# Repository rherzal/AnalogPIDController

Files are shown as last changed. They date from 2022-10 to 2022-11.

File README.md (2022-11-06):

# This is the main repository for my measurements and actuators semester project

The project is a full design and implementation of an analog PID controller pcb, using only operational amplifiers for calculations, used to control a DC motor.

It uses 3 potentiometers for setting the 3 controller constants, one potentiometer for setting the command signal, and one potentiometer for angular feedback.

The PCB was manufactured with the help of a local electronics company from Baia Mare, [circuite-imprimate.ro](https://circuite-imprimate.ro/).

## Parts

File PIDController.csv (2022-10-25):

Source: | D:\OneDrive\OneDrive - Technical University of Cluj-Napoca\Toate\Anul2\PrimulSemestru\MA\ProiectMA\PIDController\PIDController.kicad_sch
Date: | 16/10/2022 14:33:03
Tool: | Eeschema (6.0.8)
Generator: | C:\Program Files\KiCad\6.0\bin\scripting\plugins/bom_csv_grouped_by_value.py
Component Count: | 24
Individual Components:
Item | Qty | Reference(s) | Value | LibPart | Footprint | Datasheet
 |  | C1 | 4.7u | Device:C | Capacitor_THT:C_Rect_L4.6mm_W3.8mm_P2.50mm_MKS02_FKP02 | ~
 |  | C2 | 4.7u | Device:C | Capacitor_THT:C_Rect_L4.6mm_W3.8mm_P2.50mm_MKS02_FKP02 | ~
 |  | J1 | Jack-DC | Connector:Jack-DC | Connector_BarrelJack:BarrelJack_GCT_DCJ200-10-A_Horizontal | ~
 |  | J2 | Jack-DC | Connector:Jack-DC | Connector_BarrelJack:BarrelJack_GCT_DCJ200-10-A_Horizontal | ~
 |  | J3 | Screw_Terminal_01x02 | Connector:Screw_Terminal_01x02 | TerminalBlock_RND:TerminalBlock_RND_205-00001_1x02_P5.00mm_Horizontal | ~
 |  | Q1 | BD433 | Transistor_BJT:BD433 | Package_TO_SOT_THT:TO-126-3_Vertical | http://www.cdil.com/datasheets/bd433_42.pdf
 |  | Q2 | BD434 | Transistor_BJT:BD434 | Package_TO_SOT_THT:TO-126-3_Vertical | http://www.cdil.com/datasheets/bd433_42.pdf
 |  | R1 | 10k | Device:R | Resistor_THT:R_Axial_DIN0207_L6.3mm_D2.5mm_P15.24mm_Horizontal | ~
 |  | R2 | 10k | Device:R | Resistor_THT:R_Axial_DIN0207_L6.3mm_D2.5mm_P15.24mm_Horizontal | ~
 |  | R3 | 10k | Device:R | Resistor_THT:R_Axial_DIN0207_L6.3mm_D2.5mm_P15.24mm_Horizontal | ~
 |  | R4 | 10k | Device:R | Resistor_THT:R_Axial_DIN0207_L6.3mm_D2.5mm_P15.24mm_Horizontal | ~
 |  | R5 | 100k | Device:R | Resistor_THT:R_Axial_DIN0207_L6.3mm_D2.5mm_P15.24mm_Horizontal | ~
 |  | R6 | 47k | Device:R | Resistor_THT:R_Axial_DIN0207_L6.3mm_D2.5mm_P15.24mm_Horizontal | ~
 |  | R7 | 10k | Device:R | Resistor_THT:R_Axial_DIN0207_L6.3mm_D2.5mm_P15.24mm_Horizontal | ~
 |  | R8 | 10k | Device:R | Resistor_THT:R_Axial_DIN0207_L6.3mm_D2.5mm_P15.24mm_Horizontal | ~
 |  | R9 | 10k | Device:R | Resistor_THT:R_Axial_DIN0207_L6.3mm_D2.5mm_P15.24mm_Horizontal | ~
 |  | R10 | 10k | Device:R | Resistor_THT:R_Axial_DIN0207_L6.3mm_D2.5mm_P15.24mm_Horizontal | ~
 |  | RV1 | 100k | Device:R_Potentiometer | Potentiometer_THT:Potentiometer_Piher_PC-16_Single_Horizontal | ~
 |  | RV2 | 100k | Device:R_Potentiometer | Potentiometer_THT:Potentiometer_Piher_PC-16_Single_Horizontal | ~
 |  | RV3 | 100k | Device:R_Potentiometer | Potentiometer_THT:Potentiometer_Piher_PC-16_Single_Horizontal | ~
 |  | RV4 | 100k | Device:R_Potentiometer | Potentiometer_THT:Potentiometer_Piher_PC-16_Single_Horizontal | ~
 |  | RV5 | 470k | Device:R_Potentiometer | Potentiometer_THT:Potentiometer_Piher_PC-16_Single_Horizontal | ~
 |  | U1 | LM324 | Amplifier_Operational:LM324 | Package_DIP:DIP-14_W7.62mm_Socket | http://www.ti.com/lit/ds/symlink/lm2902-n.pdf
 |  | U2 | LM324 | Amplifier_Operational:LM324 | Package_DIP:DIP-14_W7.62mm_Socket | http://www.ti.com/lit/ds/symlink/lm2902-n.pdf
Collated Components:
Item | Qty | Reference(s) | Value | LibPart | Footprint | Datasheet
1 | 2 | C1, C2 | 4.7u | Device:C | Capacitor_THT:C_Rect_L4.6mm_W3.8mm_P2.50mm_MKS02_FKP02 | ~
2 | 2 | J1, J2 | Jack-DC | Connector:Jack-DC | Connector_BarrelJack:BarrelJack_GCT_DCJ200-10-A_Horizontal | ~
3 | 1 | J3 | Screw_Terminal_01x02 | Connector:Screw_Terminal_01x02 | TerminalBlock_RND:TerminalBlock_RND_205-00001_1x02_P5.00mm_Horizontal | ~
4 | 1 | Q1 | BD433 | Transistor_BJT:BD433 | Package_TO_SOT_THT:TO-126-3_Vertical | http://www.cdil.com/datasheets/bd433_42.pdf
5 | 1 | Q2 | BD434 | Transistor_BJT:BD434 | Package_TO_SOT_THT:TO-126-3_Vertical | http://www.cdil.com/datasheets/bd433_42.pdf
6 | 8 | R1, R2, R3, R4, R7, R8, R9, R10 | 10k | Device:R | Resistor_THT:R_Axial_DIN0207_L6.3mm_D2.5mm_P15.24mm_Horizontal | ~
7 | 1 | R5 | 100k | Device:R | Resistor_THT:R_Axial_DIN0207_L6.3mm_D2.5mm_P15.24mm_Horizontal | ~
8 | 1 | R6 | 47k | Device:R | Resistor_THT:R_Axial_DIN0207_L6.3mm_D2.5mm_P15.24mm_Horizontal | ~
9 | 4 | RV1, RV2, RV3, RV4 | 100k | Device:R_Potentiometer | Potentiometer_THT:Potentiometer_Piher_PC-16_Single_Horizontal | ~
10 | 1 | RV5 | 470k | Device:R_Potentiometer | Potentiometer_THT:Potentiometer_Piher_PC-16_Single_Horizontal | ~
11 | 2 | U1, U2 | LM324 | Amplifier_Operational:LM324 | Package_DIP:DIP-14_W7.62mm_Socket | http://www.ti.com/lit/ds/symlink/lm2902-n.pdf

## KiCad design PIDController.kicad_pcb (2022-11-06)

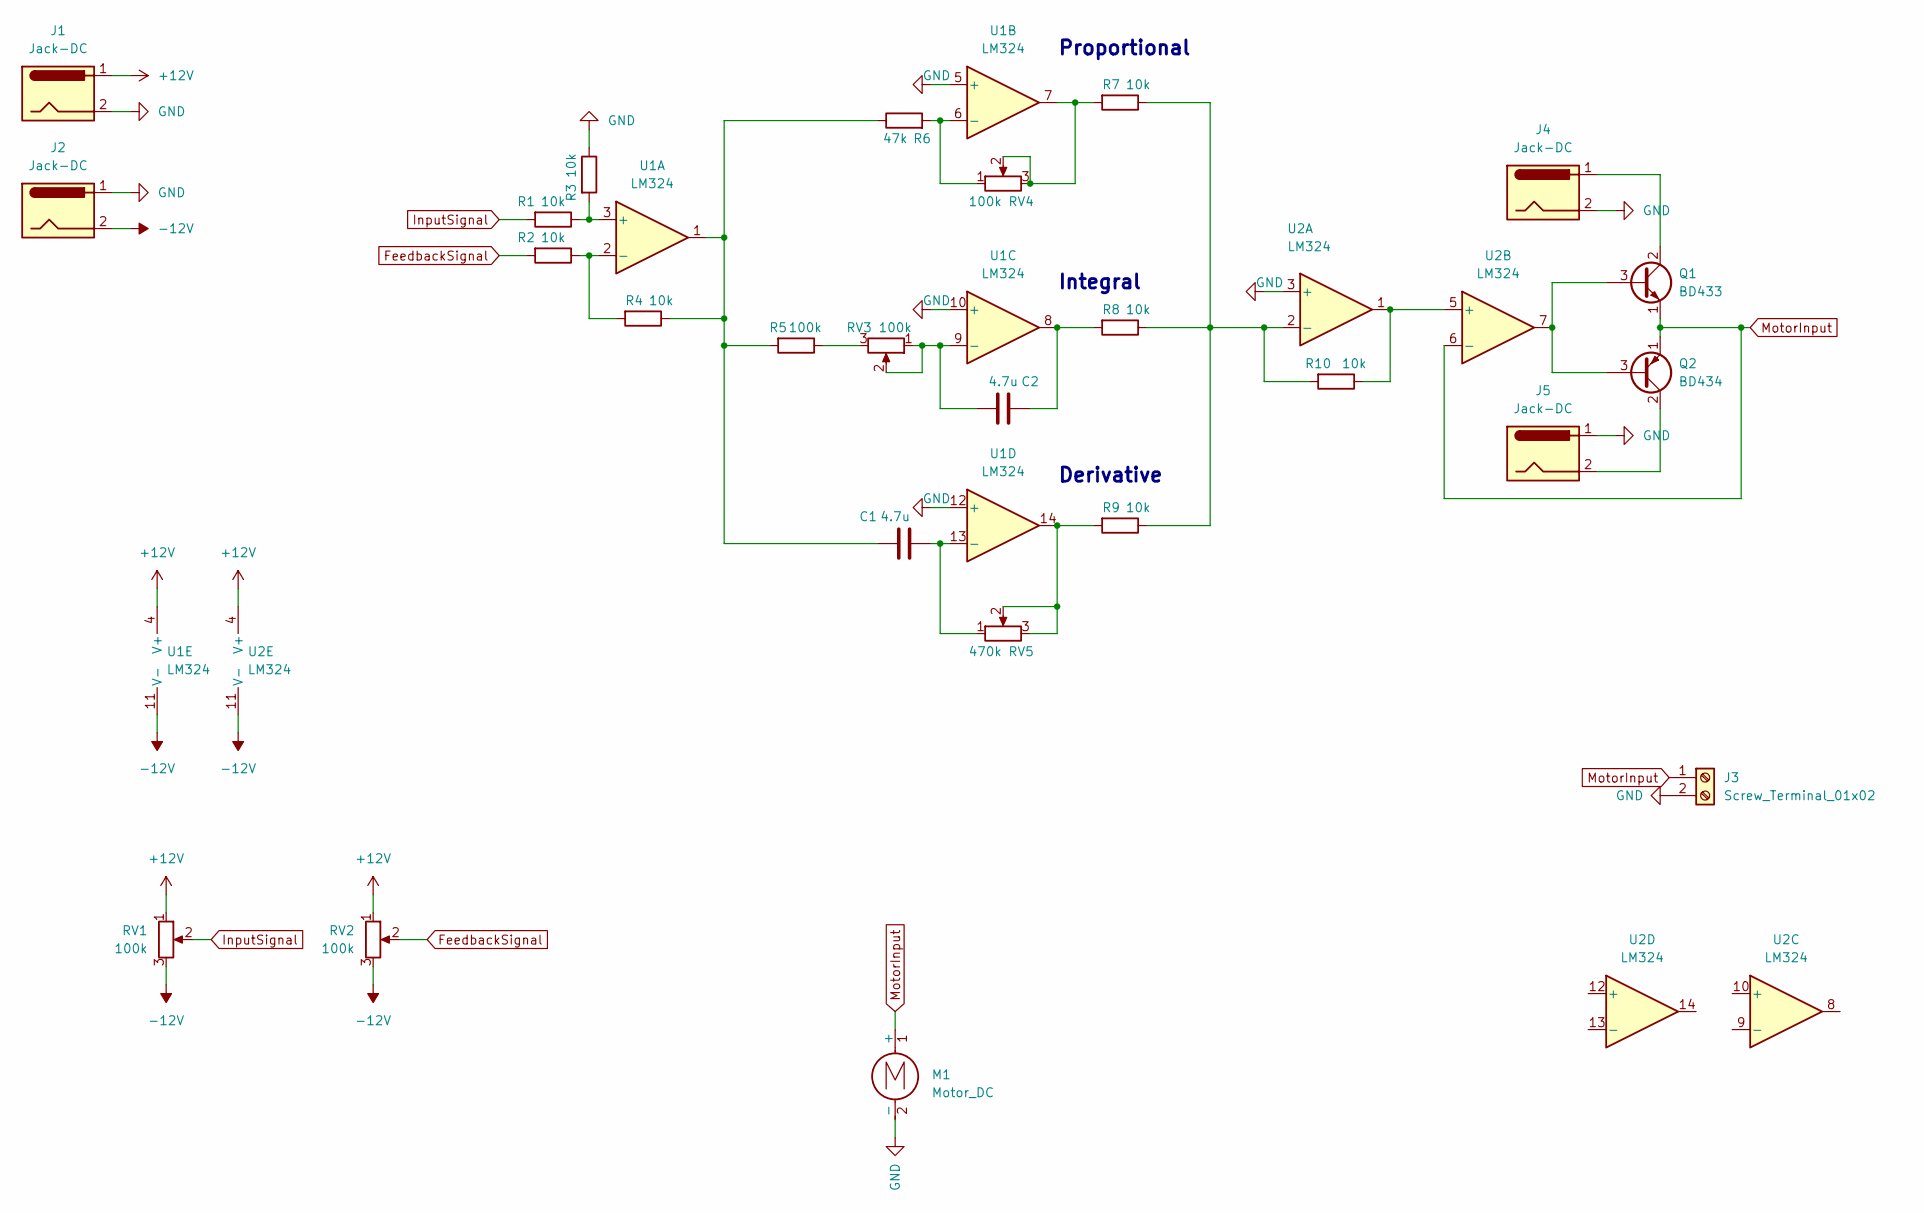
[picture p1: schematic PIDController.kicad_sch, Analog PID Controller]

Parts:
C1, C2: 4.7u; C_Rect_L4.6mm_W3.8mm_P2.50mm_MKS02_FKP02
J1, J2, J4, J5: Jack-DC; BarrelJack_GCT_DCJ200-10-A_Horizontal
J3: Screw_Terminal_01x02; TerminalBlock_RND_205-00001_1x02_P5.00mm_Horizontal
M1: Motor_DC; TerminalBlock_RND_205-00001_1x02_P5.00mm_Horizontal
Q1: BD433; TO-126-3_Vertical
Q2: BD434; TO-126-3_Vertical
R1, R2, R3, R4, R7, R8, R9, R10: 10k; R_Axial_DIN0207_L6.3mm_D2.5mm_P15.24mm_Horizontal
R5: 100k; R_Axial_DIN0207_L6.3mm_D2.5mm_P15.24mm_Horizontal
R6: 47k; R_Axial_DIN0207_L6.3mm_D2.5mm_P15.24mm_Horizontal
RV1, RV2, RV3, RV4: 100k; Potentiometer_Piher_PC-16_Single_Horizontal
RV5: 470k; Potentiometer_Piher_PC-16_Single_Horizontal
U1, U2: LM324; DIP-14_W7.62mm_Socket

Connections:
+12V: J1.1, RV1.1, RV2.1, U1.4 (V+), U2.4 (V+)
-12V: J2.2, RV1.3, RV2.3, U1.11 (V-), U2.11 (V-)
FeedbackSignal: R2.2, RV2.2
GND: J1.2, J2.1, J3.2, J4.2, J5.1, M1.2 (-), R3.1, U1.5 (+), U1.10 (+), U1.12 (+), U2.3 (+)
InputSignal: R1.2, RV1.2
MotorInput: J3.1, M1.1 (+), Q1.1 (E), Q2.1 (E), U2.6 (-)
unnamed: C1.1, R4.1, R5.2, R6.1, U1.1
unnamed: C1.2, RV5.1, U1.13 (-)
unnamed: C2.1, RV3.1, RV3.2, U1.9 (-)
unnamed: C2.2, R8.2, U1.8
unnamed: J4.1, Q1.2 (C)
unnamed: J5.2, Q2.2 (C)
unnamed: Q1.3 (B), Q2.3 (B), U2.7
unnamed: R1.1, R3.2, U1.3 (+)
unnamed: R2.1, R4.2, U1.2 (-)
unnamed: R5.1, RV3.3
unnamed: R6.2, RV4.1, U1.6 (-)
unnamed: R7.2, RV4.2, RV4.3, U1.7
unnamed: R9.2, RV5.2, RV5.3, U1.14
unnamed: R10.1, U2.1, U2.5 (+)
unnamed: R7.1, R8.1, R9.1, R10.2, U2.2 (-)

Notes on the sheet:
Proportional
Integral
Derivative

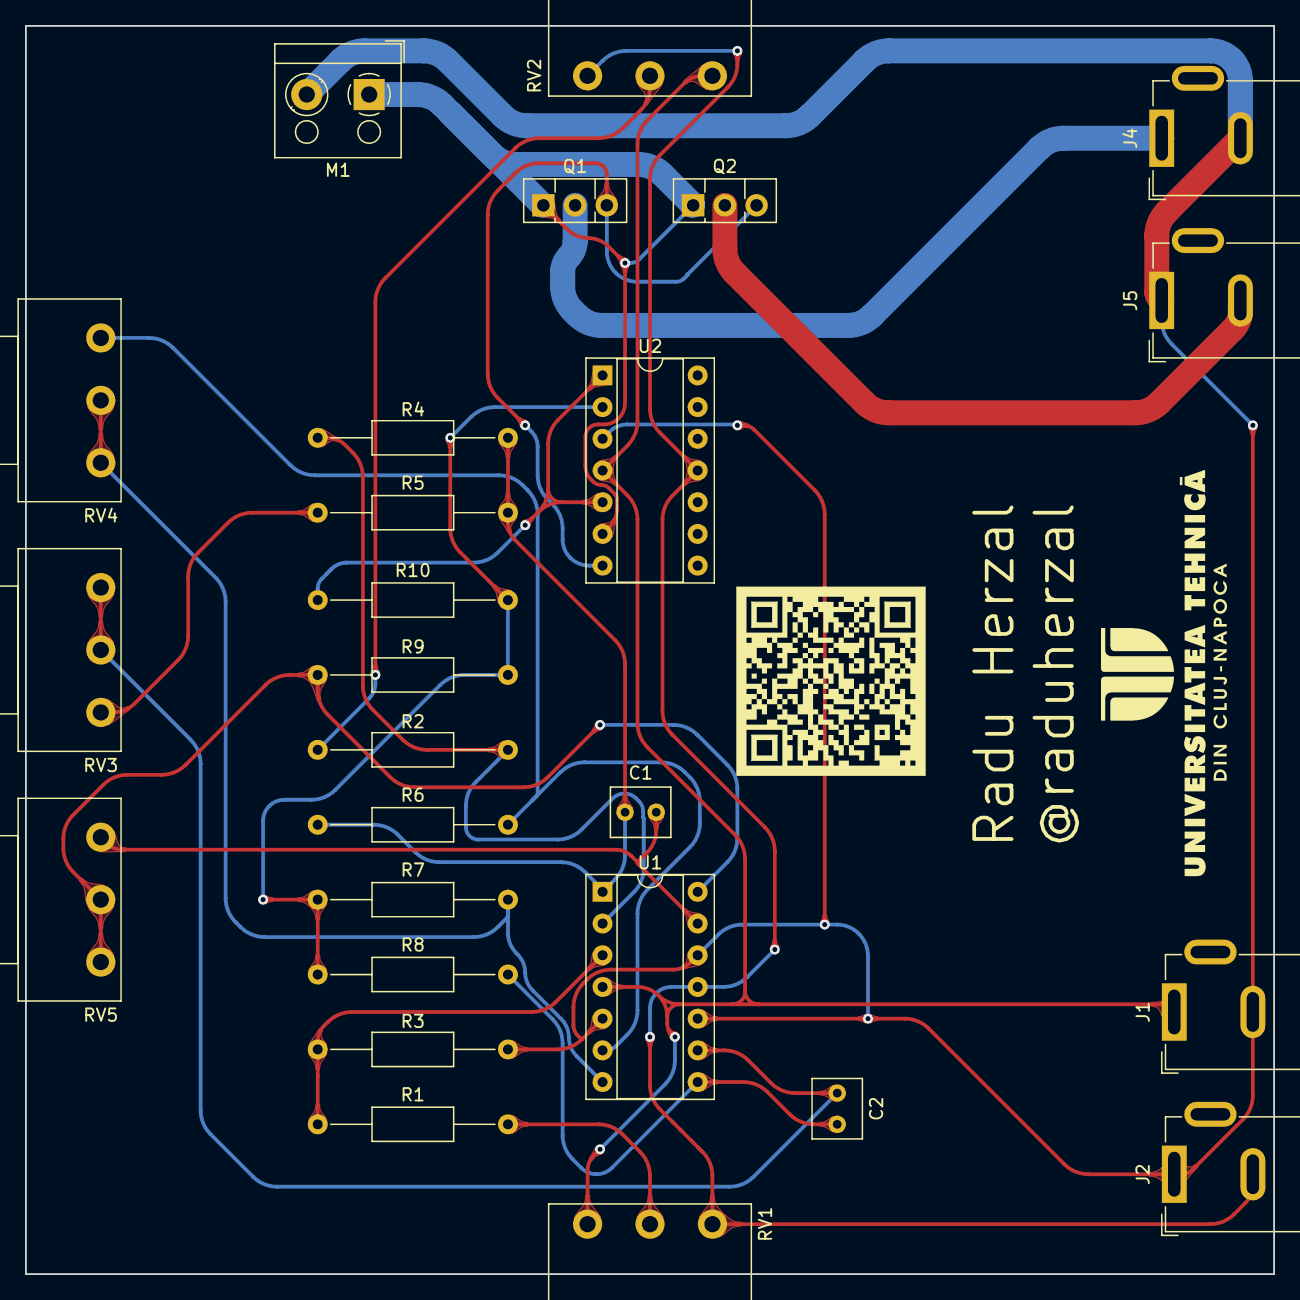
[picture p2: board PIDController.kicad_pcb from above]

Board: 2 copper layers, 100.0 x 100.0 mm, 26 parts (0 on the bottom side), 21 nets.

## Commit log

2022-11-06 improved the general design, added ground plane, silkmask etc.
    [PIDController - Copy - Copy.kicad_pcb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]
2022-11-06 changed sponsor link
    [PIDController - Copy-B_Cu.gbr, PIDController - Copy-B_Mask.gbr, PIDController - Copy-B_Paste.gbr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]
